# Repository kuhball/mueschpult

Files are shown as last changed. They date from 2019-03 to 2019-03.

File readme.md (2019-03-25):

# Müschpult 2
Dokumentation des Mischpults für die Jupibar im Gängeviertel. Hier werden 2 Stereo Ausgänge für zwei Barbereiche mit eigener Lautstärkerregelung benötigt. Das Grundgerät ist eine Yamaha DME 24N. Hierfür wurde mithilfe eines Arduino Nanos eine RS232 Fernbedienung gebaut.

## Anforderung
1. RS232 mit DME sprechen
2. Input von Potis & Schaltern auf DME setzen
3. DME Werte auf LEDs anzeigen

## geänderte Header Dateien
HardwareSerial.h

#define SERIAL_RX_BUFFER_SIZE 256

Der Compiler erkennt u.U. nicht das diese Datei geändert wurde. 
Es ist also ratsam an entsprechender stelle im Projekt die vom Compuler erstellte Objektdateie HardwareSerial.cpp.o zu löschen, damit sie neu kompiliert wird.

## Hardware
### Mux 74HC4051
8 Kanal analog Multiplexer für Input Potis. Hiervon wurden 3 Stück eingesetzt. Alle 3 werden zeitgleich gesetzt und dann am entsprechenden Pin ausgelesen.
Pins für lesen:
- A3
- A4
- A5

Pins für setzen des Zustands:
- A0
- A1
- A2

### Ledbar Treiber Shiftregister 74HC595
3 in Reihe geschaltete Schieberegister betreiben zwei 10 segment Ledbars die den Ausgangspregel der DME an die Anlage darstellen.
- Clock Pin D2
- Latch Pin D3
- Data Pin D4

## DME Setup Liste

- Talkover für Mikrofone 50 / 51 (mic1, mic2) - binär 1/0

- Fader Volume 54 / 55 (mic1, mic2) -  min -13801, max 1000
- Meter 56 (alle Meter)
  - 0 - alle Meter?
  - 1 - Input DJ Oben
  - 2 - Input Bar
  - 3 - Spare Input
  - 4 - Output Level Oben
  - 5 - Output Level Bar
  - 7 - Mic 1 Level
  - 8 - Mic 2 Level
- Input Level Stereo in 1(DJ) - 58/59  min -13801, max 1000
- Input Level Stereo in 2(Bar) - 60/61 min -13801, max 1000
- Input Level Stereo in 3(Spare) - 62/63 min -13801, max 1000
- Masterlevel Oben - 64/65
- Masterlevel Bar - 66/67

- EQ Oben:
  - High 70
  - Mid 71
  - Low 72
- EQ Bar:
  - High 73
  - Mid 74
  - Low 75
  
In der DME angelegt aber am Müschpult nicht vorhanden  
- 6 - Output Level Keller
- Mute für Mikrofone 52 / 53 (mic1, mic2) - 0/1
- EQ Keller
  - High 76
  - Mid 77
  - Low 78
- Masterlevel Keller - 68/69

## Inputs Arduino
### MUX 0
| Name | Pin  | DME  |
| --- | ---- | ---- |
| n.c. | 0 | 50 |
| n.c. | 1 | 53 |
| n.c. | 2 | 58 |
| n.c. | 3 | 64 |
| n.c. | 4 | 70 |
| Talkover Mic2  | 5 | 73 |
| Delay Switch | 6 | 76 |
| Talkover Mic1  | 7 | ?? |

## MUX 1
| Name | Pin  | DME  |
| --- | ---- | ---- |
| n.c. | 0 | 51 |
| Vol in Spare  | 1 | 54 |
| Vol in Bar | 2 | 60 |
| n.c. | 3 | 66 |
| Vol in DJ | 4 | 71 |
| n.c. | 5 | 74 |
| n.c. | 6 | 77 |
| n.c. | 7 | |

## MUX 2
| Name | Pin  | DME  |
| --- | ---- | ---- |
| EQ_Bar_Lo | 0 | 52 |
| EQ_Bar_Mid | 1 | 55 |
| EQ_Bar_Hi | 2 | 62 |
| Vol_Bar | 3 | 68 |
| EQ_Oben_Hi | 4 | 72 |
| EQ_Oben_Mid | 5 | 75 |
| EQ_Oben_Mid | 6 | 78 |
| EQ_Oben_Lo | 7 | |

## DME Meter

!!! Zum Verarbeiten des langen Antwortstrings der DME wurde der Serielle Buffer vergrößert.
Hierfür wurde die variable SERIAL_RX_BUFFER_SIZE in der HardwareSerial.h auf 256 gesetzt.
http://shelvin.de/arduino-serial-buffer-size-aendern/

Beispielantwort der DME auf ein `GMT 0 56 0`.
```
MTR 0 56 0 CUR -13801 -13801 -13801 -6000 -13801 -13801 -13801 -13801 -13801 -13801 -13801 -13801 -13801 -13801 -13801 -13801 HOLD -9322 -9741 -9332 -13801 -7421 -8943 -8943 -13801 -13801 -13801 -13801 -13801 -13801 -13801 -13801 -13801

MTR 0 56 0 CUR -13801 -13801 -13801 -13801 -13801 -13801 -13801 -13801 HOLD -9322 -9741 -9332 -13801 -7421 -8943 -8943 -13801
MTR 0 56 0 CUR 1 1 1 1 1 1 1 1 HOLD -9322 -9741 -9332 -13801 -7421 -8943 -8943 -13801

```

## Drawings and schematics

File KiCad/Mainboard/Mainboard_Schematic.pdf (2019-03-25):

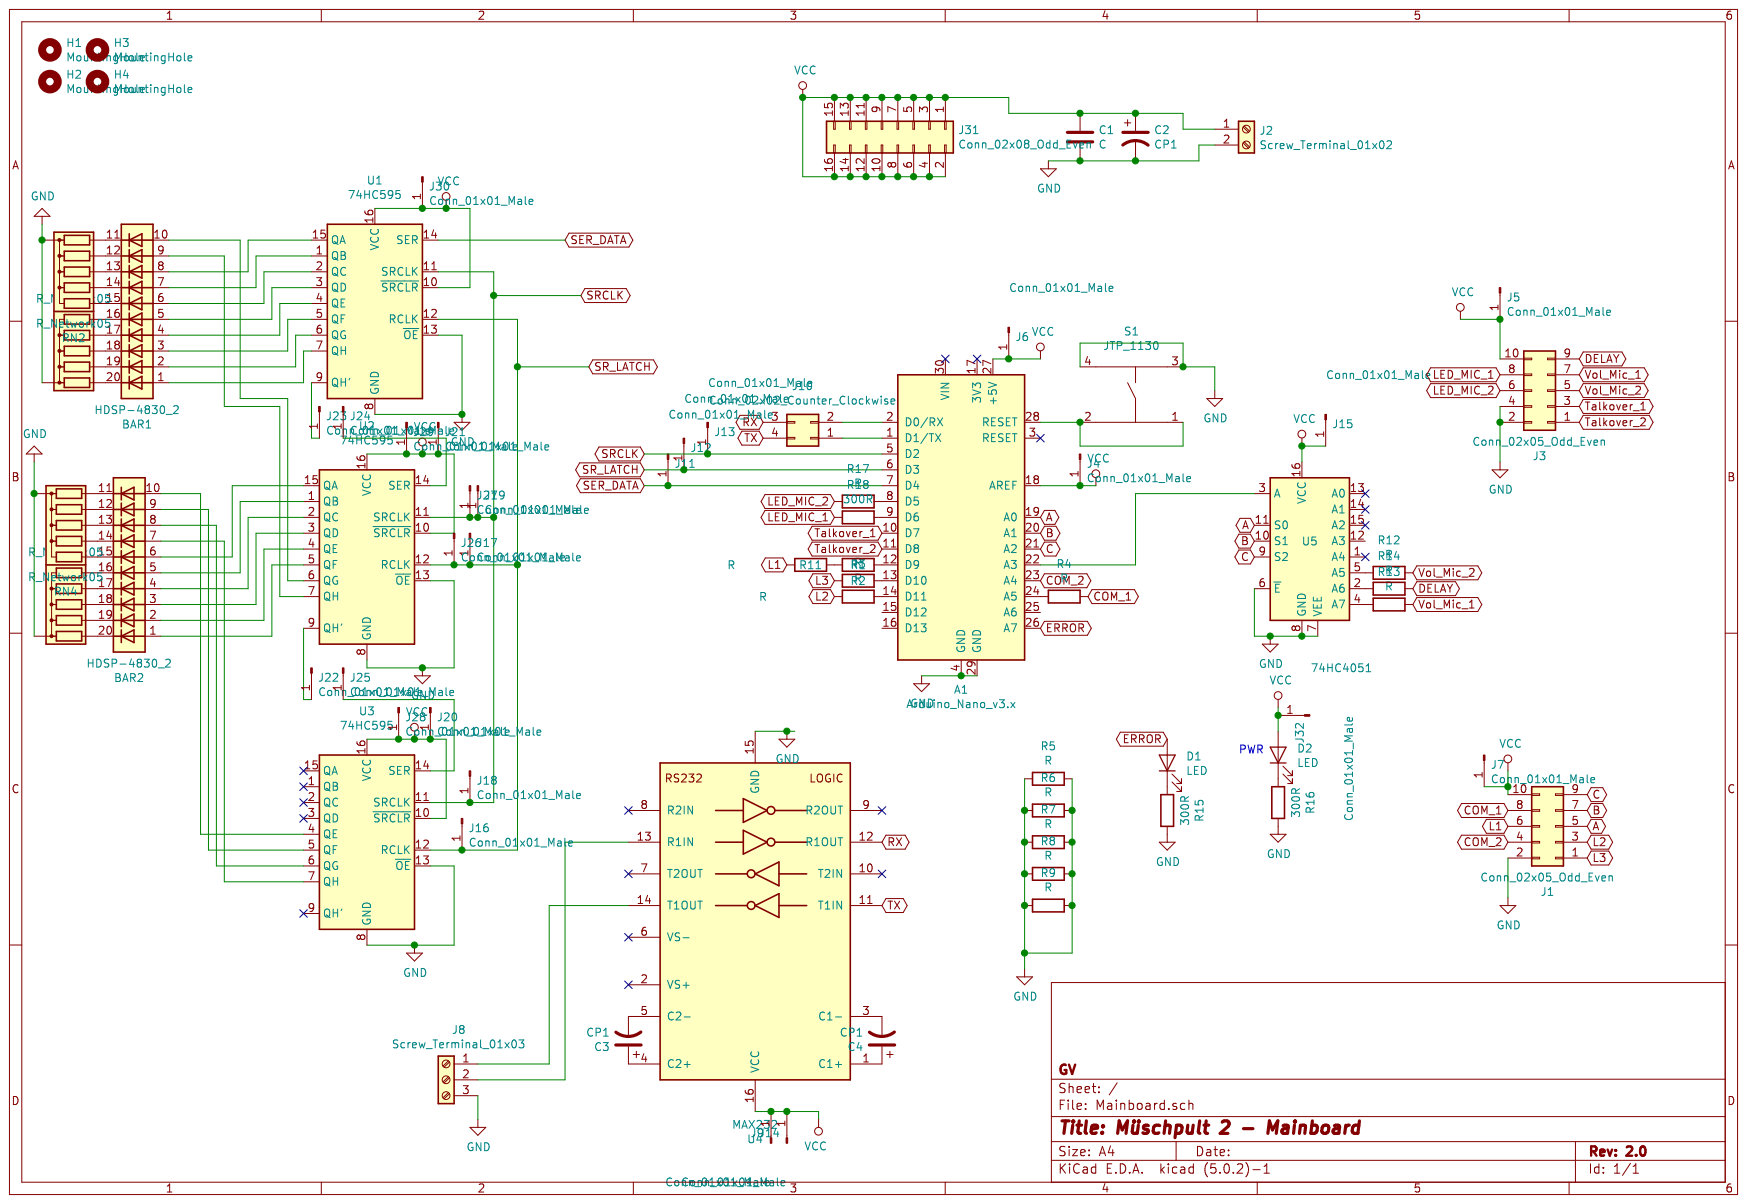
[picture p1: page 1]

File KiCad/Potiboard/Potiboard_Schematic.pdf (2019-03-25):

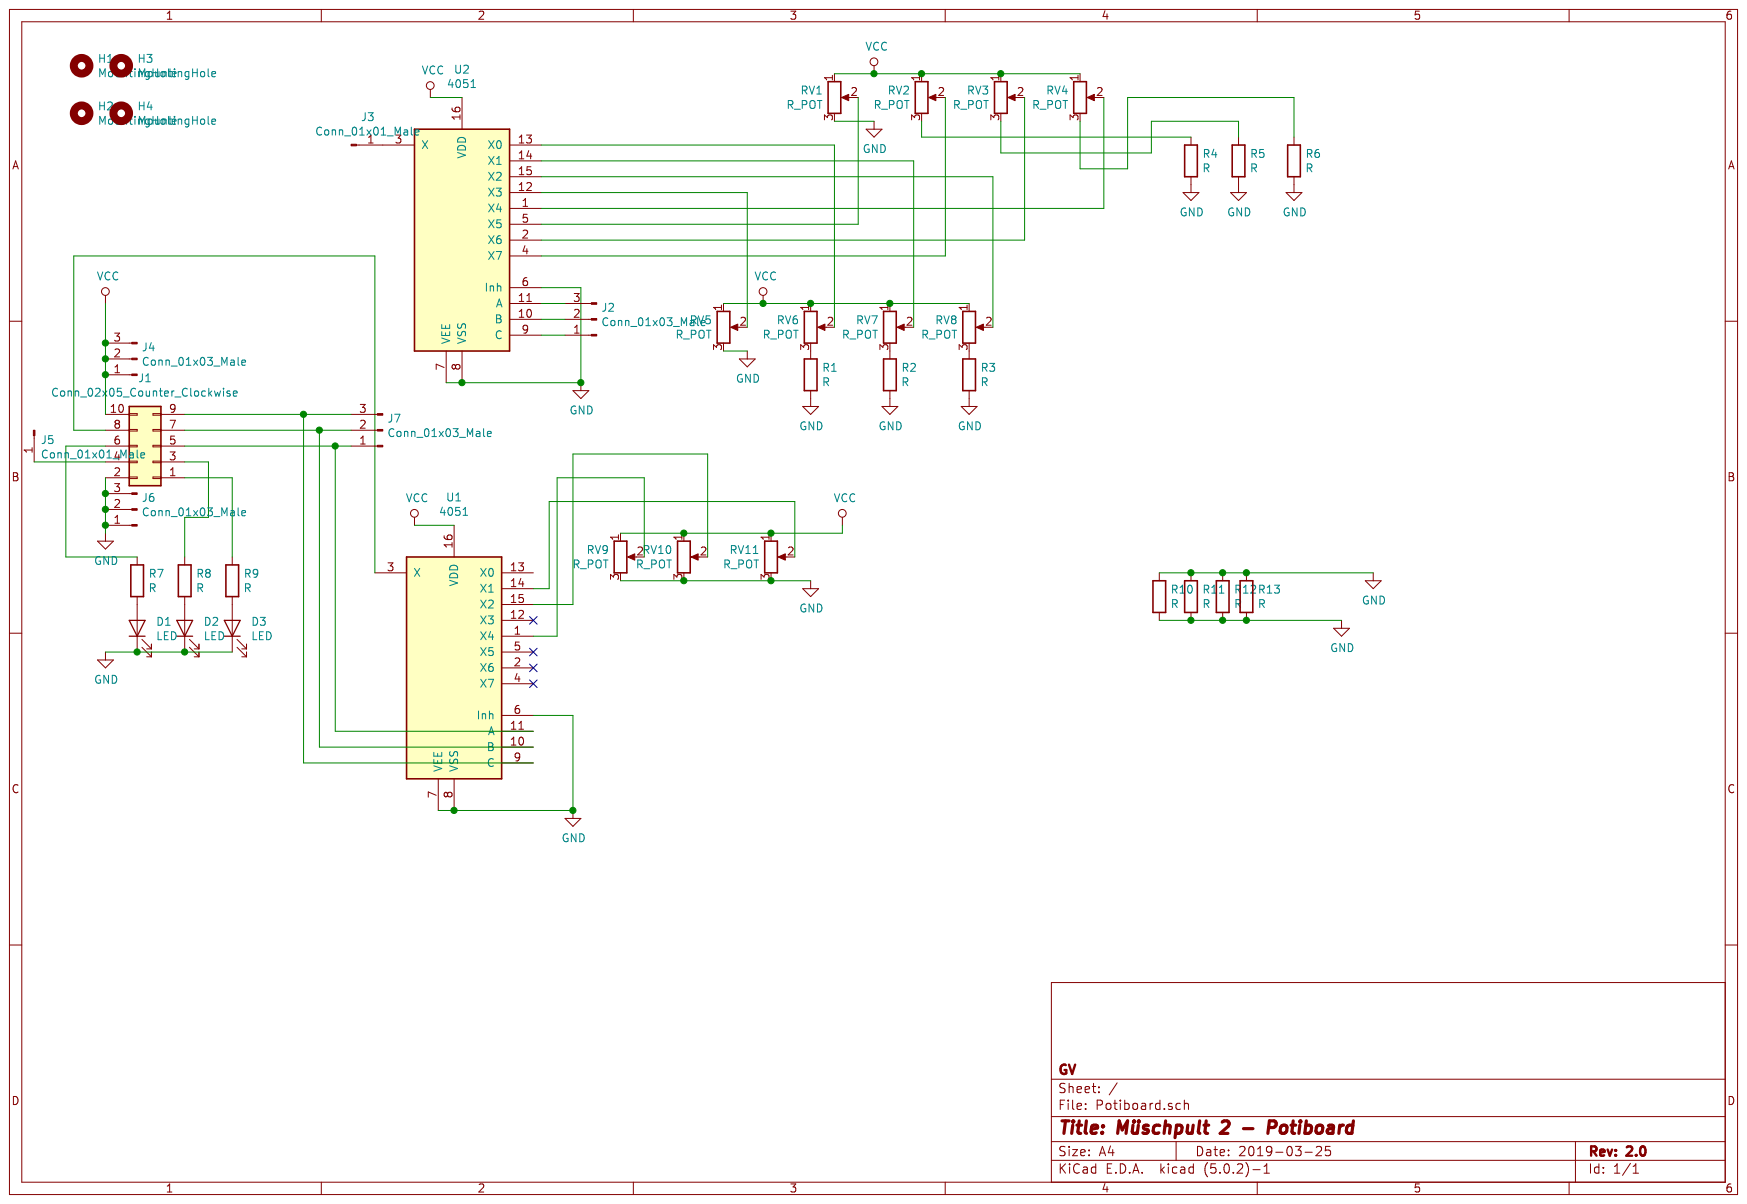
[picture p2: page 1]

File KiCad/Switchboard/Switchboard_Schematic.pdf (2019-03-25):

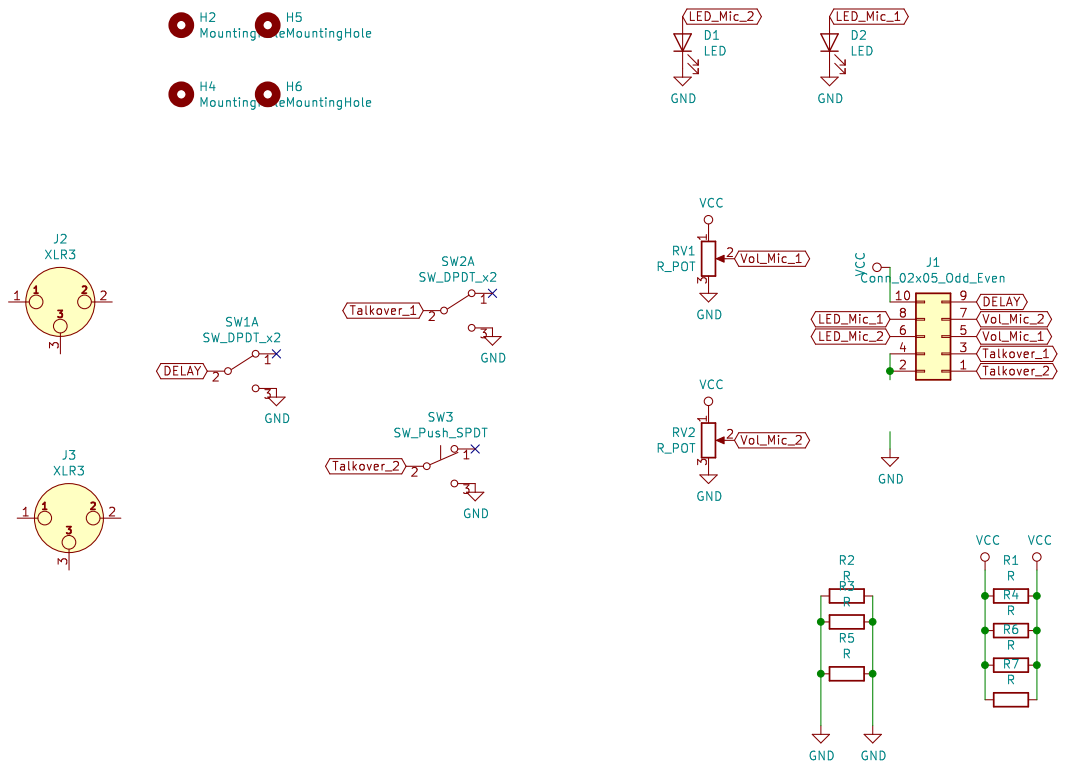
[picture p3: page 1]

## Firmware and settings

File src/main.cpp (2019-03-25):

/*INCLUDES*/
#include <Arduino.h>


/*DEBUG macros*/
#define DEBUG   //If you comment this line, the DPRINT & DPRINTLN lines are defined as blank.
#ifdef DEBUG    //Macros are usually in all capital letters.
#define DPRINT(...)    Serial.print(__VA_ARGS__)     //DPRINT is a macro, debug print
#define DPRINTLN(...)  Serial.println(__VA_ARGS__)   //DPRINTLN is a macro, debug print with new line
#else
#define DPRINT(...)     //now defines a blank line
#define DPRINTLN(...)   //now defines a blank line
#endif

/*DEFINES*/

#define SERIAL_BAUD 38400

/* LEDS */
#define LED_INPUT_DJ 9
#define LED_INPUT_BAR 11
#define LED_INPUT_SPARE 10

#define ERROR_LED 13

#define LED_MIC_1 5
#define LED_MIC_2 6

/* Switch Pins */
#define SW_PIN_TO_1 7
#define SW_PIN_TO_2 11

/*Shift Register Pins*/
#define SCLK_PIN 2
#define SR_LATCH_PIN 3
#define SER_DATA_PIN 4


/*MUX STUFF*/
// read pins
#define PIN_MUX0 A3
#define PIN_MUX1 A5
#define PIN_MUX2 A4

// write pins for setting mux channel
#define MUX_S0 A0
#define MUX_S1 A1
#define MUX_S2 A2
/*MUX STUFF*/
/*
Mux_S0
Mux on Mainboard A0 - A4 N.C.
X5->Vol_Mic_2
X6->DELAY_SW
X7->Vol_Mic_1

MUX_S1(COM_1) Input Vol
X4->Vol DJ
X2->Vol_Bar
X1->Vol Spare

MUX_S2(COM_2) EQ and PA Vol

X0->EQ_BAR_LO
X1->EQ_BAR_MID
X2->EQ_BAR_HI
X3->VOL_BAR
X4->EQ_OBEN_HI
X5->VOL_OBEN
X6->EQ_OBEN_MID
X7->EQ_OBEN_LO


* /
/*
enum Mux_0 { VOL_MIC_2 = 5, DELAY_SW = 6, VOL_MIC_1 = 7 };
enum Mux_1 { VOL_INPUT_DJ = 4, VOL_INPUT_BAR = 2, VOL_INPUT_SPARE = 1 };
enum Mux_2 { EQ_BAR_LO, EQ_OBEN_HI, EQ_BAR_HI, EQ_OBEN_MID, EQ_BAR_MID, VOL_OBEN, VOL_BAR, EQ_OBEN_LO };

Mux_2 mux2;
Mux_1 mux1;
Mux_0 mux0;
*/

/* Function declarations */
void Blink();
void enableError();
void disableError();
void setupPins();
void writeLedBar(int, int);


/* variables */

struct inputpin {
	int value;
	uint8_t mux;  // Mux value to read from this input
	uint8_t pin;  // Pin to read from
	uint8_t dme;  // Value needed for DME set
	bool digital; // needed to distinguish analog from digital read
	bool stereo;  // set two dme values if stereo
};

struct outputpin {
	int value;
	uint8_t out; // TLC Number
	uint8_t dme; // DME Read number
	bool bar;    // set if led bar (size 10)
};

const byte numChars = 200;        //  buffer for dme read
char receivedChars[numChars];
char tempChars[numChars];         // temporary array for use when parsing

uint8_t i = 0;
unsigned long time = millis();

boolean newData = false;

// set if outputs were updated
boolean outputUpdate = false;


/* Class definitions */



class LedBar {

public:
	void init() {
		for (int i = 0; i < 20; i++)
		{
			led[i][0] = 0;
			led[i][1] = 0;
			led[i][2] = 0;
		}
		led[19][2] = 1 << 4;
		led[18][2] = 1 << 5;
		led[17][2] = 1 << 6;
		led[16][2] = 1 << 7;
		led[15][1] = 1 << 0;
		led[14][1] = 1 << 1;
		led[13][1] = 1 << 2;
		led[12][1] = 1 << 3;
		led[11][1] = 1 << 4;
		led[10][1] = 1 << 5;
		led[9][1] = 1 << 6;
		led[8][1] = 1 << 7;
		led[7][0] = 1 << 0;
		led[6][0] = 1 << 1;
		led[5][0] = 1 << 2;
		led[4][0] = 1 << 3;
		led[3][0] = 1 << 4;
		led[2][0] = 1 << 5;
		led[1][0] = 1 << 6;
		led[0][0] = 1 << 7;

	}

	void write(int bar0, int bar1) // write erwartet für bar0 und bar1 werte vom 0 bis 10
	{
		bar0 = bar0 - 1;
		for (bar0; bar0 >= 0; bar0--)
		{
			bytes[0] |= led[bar0][0];
			bytes[1] |= led[bar0][1];
			bytes[2] |= led[bar0][2];
			/*
			Serial.write(bytes[0]);
			Serial.write(bytes[1]);
			Serial.write(bytes[2]);
			Serial.println("");
			*/
		}
		bar1 = bar1 + 9;
		for (bar1; bar1 >= 10; bar1--)
		{
			bytes[0] |= led[bar1][0];
			bytes[1] |= led[bar1][1];
			bytes[2] |= led[bar1][2];
			/*
			Serial.write(bytes[0]);
			Serial.write(bytes[1]);
			Serial.write(bytes[2]);
			Serial.println("");
			*/
		}
		sendBytes();
		clearBytes();
	}

private:
	char byte[3] = { 0,0,0 };
	char led[20][3];
	char bytes[3] = { 0,0,0 };
	void clearBytes()
	{
		bytes[0] = 0;
		bytes[1] = 0;
		bytes[2] = 0;
	}
	void sendBytes()
	{
		digitalWrite(SR_LATCH_PIN, LOW);
		shiftOut(SER_DATA_PIN, SCLK_PIN, MSBFIRST, bytes[2]);
		shiftOut(SER_DATA_PIN, SCLK_PIN, MSBFIRST, bytes[1]);
		shiftOut(SER_DATA_PIN, SCLK_PIN, MSBFIRST, bytes[0]);
		digitalWrite(SR_LATCH_PIN, HIGH);
	}

};


class Inputs {
public:
	// send command over serial to DME
	void set(inputpin input) {
		// different command for EQ
		if (input.mux < 7 && input.mux > 3) {
			// map poti value to dme value (only ±6dB)
			int level = map(input.value, 0, 1023, -600, 600);
			send(level, input.dme);
		}
		else {
			send(input.value, input.dme);
			// Setting second value -> stereo
			if (input.stereo) {
				send(input.value, input.dme + 1);
			}
		}
	};

	void update(boolean setall) {
		// setall for initialisation and sending all values to the DME
		// Looping over inputpin inputs[22]
		for (int i = 0; i < 16; i++) {
			// Changing Mux if needed - normally every 3rd time
			if (inputs[i].mux != currentMux) {
				setMux(inputs[i].mux);
				currentMux = inputs[i].mux; // saving current Mux pin
			}

			// analog / digital read the input pin
			int cache = readPin(inputs[i].pin, inputs[i].digital);


			// debouncing value - only values with a bigger difference than 3 are send
			if (cache < inputs[i].value - 3 || cache > inputs[i].value + 3 || setall) {
				inputs[i].value = cache;
				set(inputs[i]);
			}
			else if ((inputs[i].digital && cache != inputs[i].value) || setall) { // digital always
				inputs[i].value = cache;
				set(inputs[i]);
			}
		}
	};
private:
	/*
		Mux_S0
		Mux on Mainboard A0 - A4 N.C.
		X5->Vol_Mic_2
		X6->DELAY_SW
		X7->Vol_Mic_1

		MUX_S1(COM_1) Input Vol
		X4->Vol DJ
		X2->Vol_Bar
		X1->Vol Spare

		MUX_S2(COM_2) EQ and PA Vol

		X0->EQ_BAR_LO
		X1->EQ_BAR_MID
		X2->EQ_BAR_HI
		X3->VOL_BAR
		X4->EQ_OBEN_HI
		X5->VOL_OBEN
		X6->EQ_OBEN_MID
		X7->EQ_OBEN_LO


	*/
	// input array - if needed change size, for loop and add input
	// {level, mux, pin, dme, digital, stereo}
	inputpin inputs[16] = { //  old -> inputs[22]
		// SWITCHES
		{0, 0, SW_PIN_TO_1, 50, true,  false},   // Talkover Mic1
		{0, 0, SW_PIN_TO_2, 51, true,  false},   // Talkover Mic2
		//{0, 0, PIN_MUX3, 52, true,  false},   // Mute Mic1
		//{0, 1, PIN_MUX1, 53, true,  false},   // Mute Mic2
		// POTIS
		{0, 7, PIN_MUX0, 54, false, false},   // Volume Mic1
		{0, 5, PIN_MUX0, 55, false, false},   // Volume Mic2
		{0, 4, PIN_MUX1, 58, false, true},   // Input DJ
		{0, 2, PIN_MUX2, 60, false, true},   // Input Bar
		{0, 1, PIN_MUX1, 62, false, true},   // Input Spare
		{0, 5, PIN_MUX2, 64, false, true},   // Output Oben
		{0, 3, PIN_MUX2, 66, false, true},   // Output Bar
		//{0, 3, PIN_MUX2, 68, false, true},   // Output Unten
		// EQ Oben
		{0, 4, PIN_MUX2, 70, false, false},   // High
		{0, 6, PIN_MUX2, 71, false, false},   // Mid
		{0, 7, PIN_MUX2, 72, false, false},   // Low
		// EQ Bar
		{0, 2, PIN_MUX2, 73, false, false},   // High
		{0, 1, PIN_MUX2, 74, false, false},   // Mid
		{0, 0, PIN_MUX2, 75, false, false},   // Low
		// EQ Keller
		//{0, 6, PIN_MUX1, 76, false, false},   // High
		//{0, 6, PIN_MUX2, 77, false, false},   // Mid
		//{0, 6, PIN_MUX3, 78, false, false},   // Low
		// extra
		{0, 6, PIN_MUX0, 79, true,  true},    // Delay Switch
	};

	// cached mux pin
	uint8_t currentMux;

	// read analog / digital pin
	int readPin(uint8_t pin, bool digital) {
		if (!digital) {
			return analogRead(pin);
		}
		else {
			return !(digitalRead(pin));
		}
	}

	// set mux pins
	void setMux(uint8_t mux) {
		switch (mux) {
		case 0:
			digitalWrite(MUX_S0, LOW);
			digitalWrite(MUX_S1, LOW);
			digitalWrite(MUX_S2, LOW);
			break;
		case 1:
			digitalWrite(MUX_S0, HIGH);
			digitalWrite(MUX_S1, LOW);
			digitalWrite(MUX_S2, LOW);
			break;
		case 2:
			digitalWrite(MUX_S0, LOW);
			digitalWrite(MUX_S1, HIGH);
			digitalWrite(MUX_S2, LOW);
			break;
		case 3:
			digitalWrite(MUX_S0, HIGH);
			digitalWrite(MUX_S1, HIGH);
			digitalWrite(MUX_S2, LOW);
			break;
		case 4:
			digitalWrite(MUX_S0, LOW);
			digitalWrite(MUX_S1, LOW);
			digitalWrite(MUX_S2, HIGH);
			break;
		case 5:
			digitalWrite(MUX_S0, HIGH);
			digitalWrite(MUX_S1, LOW);
			digitalWrite(MUX_S2, HIGH);
			break;
		case 6:
			digitalWrite(MUX_S0, LOW);
			digitalWrite(MUX_S1, HIGH);
			digitalWrite(MUX_S2, HIGH);
			break;
		case 7:
			digitalWrite(MUX_S0, HIGH);
			digitalWrite(MUX_S1, HIGH);
			digitalWrite(MUX_S2, HIGH);
			break;
		default:
			break;
		};
	};

	// write dme command on serial, different command for volumes
	void send(int level, uint8_t dme) {
		if (dme < 70 && dme > 53) {
			Serial.print("SVL 0 ");
			Serial.print(dme);
			Serial.print(" ");
			Serial.print(level);
			Serial.print('\n');
		}
		else {
			Serial.print("SPR 0 ");
			Serial.print(dme);
			Serial.print(" ");
			Serial.print(level);
			Serial.print('\n');
		}
	};
};


class Outputs {
public:
	void getDME() {
		Serial.print("GMT 0 56 0 \n");
	};

	// from https://forum.arduino.cc/index.php?topic=288234.0
	void recvWithStartEndMarkers() {
		static boolean recvInProgress = false;
		static byte ndx = 0;
		char startMarker = 'U';
		char endMarker = 'H';
		char rc;

		while (Serial.available() > 0 && newData == false) {
			rc = Serial.read();

			if (recvInProgress == true) {
				if (rc != endMarker) {
					receivedChars[ndx] = rc;
					ndx++;
					if (ndx >= numChars) {
						ndx = numChars - 1;
					}
				}
				else {
					recvInProgress = false;
					ndx = 0;
					newData = true;
				}
			}
			else if (rc == startMarker) {
				recvInProgress = true;
			}
		}
	}

	void parseData() {      // split the data into its parts

		char *strtokIndx; // this is used by strtok() as an index

		strtokIndx = strtok(tempChars, " ");      // get the first part - the string

		// read the first 8 values of DME response
		// MTR 0 56 0 CUR -9428 -9780 -9376 -13801 -7432 -9004 -9004 -13801 -13801 -13801 -13801 -13801 -13801 -13801 -13801 -13801 HOLD -9322 -9741 -9332 -13801 -7421 -8943 -8943 -13801 -13801 -13801 -13801 -13801 -13801 -13801 -13801 -13801
		for (uint8_t i = 0; i < 7; i++) {
			strtokIndx = strtok(NULL, " ");      // get the first part - the string
			outputs[i].value = atoi(strtokIndx);     // convert this part to an integer
			set(outputs[i]);
		}
		outputUpdate = true;
	}

	/*
struct outputpin {
	int value;
	uint8_t out; // TLC Number
	uint8_t dme; // DME Read number
	bool bar;    // set if led bar (size 10)
};*/

// set LED Bar output
	void set(outputpin out) {
		if (out.bar)
		{
			// map DME value to 10 LEDs, not dimmed
			int level = map(out.value, -13801, 1, 0, 10);
			writeLedBar(out.out, level);

		}
		else {
			// map DME value to 1 LED, dimmed
			int level = map(out.value, -13801, 1, 0, 255);
			analogWrite(out.out, level);
		}
	}
	void setTest(int b0, int b1)
	{
		writeLedBar(b0, b1);
	}


private:
	// output array {level, Bar number, DME number, bar}
	outputpin outputs[7] = {
			{0, LED_INPUT_DJ, 1,  false}, // input DJ oben
			{0, LED_INPUT_BAR, 2,  false}, // input Bar
			{0, LED_INPUT_SPARE, 3,  false}, // input spare
			{0, 0,  5,  true},  // Output Oben Level
			{0, 1, 6,  true},  // Output Bar Level
			//{0, 33, 7,  true},  // Output Keller Level
			{0, LED_MIC_1, 15, false}, // Mic1 Level
			{0, LED_MIC_2, 16, false}, // Mic2 Level
	};

};


/* Declaring Classes*/

class Inputs;
class Outputs;
class LedBar;

// Creating class objects
Inputs inputs;
Outputs outputs;
LedBar ledBar;

void setup() {
	pinMode(ERROR_LED, OUTPUT);
	enableError();
	// Start Serial - BAUD set in define
	Serial.begin(SERIAL_BAUD);
	setupPins();
	ledBar.init();


	// send all poti values to dme for initialisation
	inputs.update(true);

	// receive all dme values
	outputs.getDME();

	disableError();
	Blink();
};

void loop() {
	/*
	//update all inputs and send to dme
	if (millis() - time > 100) {
		inputs.update(false);
		while (Serial.available() > 0) {
			Serial.read();
		}
		outputs.getDME();
		time = millis();
	}
	*/

	// // send command for new outputs every 3rd loop & enable Error if no DME response
	// if (i > 5 && outputUpdate) {
	//
	//     outputUpdate = false;
	//     disableError();
	//     i=0;
	// } else if (i > 20 && !outputUpdate){
	//     outputs.getDME();
	//     enableError();
	// }
	// i++;
	// read buffer and check for start / end markers
	/*
	outputs.recvWithStartEndMarkers();
	if (newData == true) {
		strcpy(tempChars, receivedChars);
		// this temporary copy is necessary to protect the original data
		//   because strtok() used in parseData() replaces the commas with \0
		//Tlc.clear();
		outputs.parseData();
		newData = false;
	}
	*/
	for (int i = 0; i <= 10; i++)
	{
		//ledBar.write(i, i);
		outputs.setTest(i, i);
		delay(200);
	}
	DPRINTLN("loop done");

	// TODO: enable error LED if no answer from DME
	// TODO: test this shit!
};


/* Function Definitions */

// Startup animation
void Blink()
{
	for (int i = 0; i < 255; i++)
	{
		analogWrite(LED_BUILTIN, i);
		analogWrite(LED_INPUT_BAR, i);
		analogWrite(LED_INPUT_DJ, i);
		analogWrite(LED_INPUT_SPARE, i);
		analogWrite(LED_MIC_1, i);
		analogWrite(LED_MIC_2, i);
		delay(2);
	}
	for (int i = 255; i > 0; i--)
	{
		analogWrite(LED_BUILTIN, i);
		analogWrite(LED_INPUT_BAR, i);
		analogWrite(LED_INPUT_DJ, i);
		analogWrite(LED_INPUT_SPARE, i);
		analogWrite(LED_MIC_1, i);
		analogWrite(LED_MIC_2, i);
		delay(2);
	}
	for (int i = 0; i < 10; i++)
	{
		ledBar.write(i, 0);
		delay(20);
	}
	for (int i = 0; i < 10; i++)
	{
		ledBar.write(0, i);
		delay(20);
	}

	delay(200);

	analogWrite(LED_BUILTIN, 255);
	analogWrite(LED_INPUT_BAR, 255);
	analogWrite(LED_INPUT_DJ, 255);
	analogWrite(LED_INPUT_SPARE, 255);
	analogWrite(LED_MIC_1, 255);
	analogWrite(LED_MIC_2, 255);
	ledBar.write(10, 10);
	delay(200);

	analogWrite(LED_BUILTIN, 0);
	analogWrite(LED_INPUT_BAR, 0);
	analogWrite(LED_INPUT_DJ, 0);
	analogWrite(LED_INPUT_SPARE, 0);
	analogWrite(LED_MIC_1, 0);
	analogWrite(LED_MIC_2, 0);
	ledBar.write(0, 0);
	delay(200);

	analogWrite(LED_BUILTIN, 255);
	analogWrite(LED_INPUT_BAR, 255);
	analogWrite(LED_INPUT_DJ, 255);
	analogWrite(LED_INPUT_SPARE, 255);
	analogWrite(LED_MIC_1, 255);
	analogWrite(LED_MIC_2, 255);
	ledBar.write(10, 10);
	delay(200);

	analogWrite(LED_BUILTIN, 0);
	analogWrite(LED_INPUT_BAR, 0);
	analogWrite(LED_INPUT_DJ, 0);
	analogWrite(LED_INPUT_SPARE, 0);
	analogWrite(LED_MIC_1, 0);
	analogWrite(LED_MIC_2, 0);
	ledBar.write(0, 0);
	delay(200);
}

// enable error led
void enableError() {
	digitalWrite(ERROR_LED, HIGH);
}

// disable Error led
void disableError() {
	digitalWrite(ERROR_LED, LOW);
}

void setupPins() {
	pinMode(PIN_MUX0, INPUT);
	pinMode(PIN_MUX1, INPUT);
	pinMode(PIN_MUX2, INPUT);

	pinMode(MUX_S0, OUTPUT);
	pinMode(MUX_S1, OUTPUT);
	pinMode(MUX_S2, OUTPUT);
	
	pinMode(SCLK_PIN, OUTPUT);
	pinMode(SR_LATCH_PIN, OUTPUT);
	pinMode(SER_DATA_PIN, OUTPUT);
	pinMode(ERROR_LED, OUTPUT);

	pinMode(SW_PIN_TO_1, INPUT_PULLUP);
	pinMode(SW_PIN_TO_2, INPUT_PULLUP);
}

void writeLedBar(int b0, int b1)
{
	ledBar.write(b0, b1);
}

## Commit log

2018-12-11 added & fixed Inputs.set method print DME command to serial port only printed if value changed added Outputs array for all outputs setBar for setting bar graph removed DME class reformated
    [main.cpp]
2018-12-11 added outputs & delay switch
2018-12-11 modified Outputs.set() distinguish bar from single LED
2018-12-12 fixed DME commands & added level mapping
    [main.cpp]
2019-01-15 on reset all values are sent to the dme and afterwords only on change
    [main.cpp]
2019-01-23 changed eq mapping - too much gain for the amps
    [main.cpp]
2019-03-25 KiCad files
    Schaltpläne und PCB Designs der drei Platinen des Müschpultes.
    [Mainboard.kicad_pcb, Mainboard.sch, Potiboard.kicad_pcb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]
2019-03-25 Updated files and folderstructure
    Updated Files and Folderstructure
    [Mainboard.kicad_pcb, Mainboard.sch, Switchboard.kicad_pcb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]
